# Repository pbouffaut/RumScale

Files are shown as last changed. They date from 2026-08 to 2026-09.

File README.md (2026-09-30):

# RumScale

**Manuel d’utilisation : [Français](https://pbouffaut.github.io/RumScale/) ·
[English](https://pbouffaut.github.io/RumScale/en/) ·
[Kréyòl Gwadloup](https://pbouffaut.github.io/RumScale/gcf/)** — première connexion,
utilisation quotidienne, Telegram, entretien, nouveau remplissage et dépannage.
Le manuel accompagne un tonneau déjà préparé ; le montage et les réparations
sont regroupés dans une annexe technique.

Un tonneau de vieillissement posé sur une base qui le pèse. Il sait combien il
reste dedans, depuis combien de jours le rhum vieillit, et il prévient quand le
niveau baisse.

- **Écran couleur** sur le tonneau : jauge de tonneau qui se vide, niveau en %,
  jours de vieillissement et réveil par deux coups brefs sur la base. Un bouton
  optionnel permet de parcourir les pages et de remettre le vieillissement à zéro.
- **App web** servie par l'ESP32 lui-même : jauge, historique, journal des
  services, assistant d'initialisation. Aucune application à installer — ça
  s'ouvre dans le navigateur, sur iPhone comme sur Android.
- **Alertes Telegram** à chaque service et aux seuils de 50 %, 25 % et 10 %.

---

## 1. Matériel

| Élément | Détail |
|---|---|
| Carte | **ideaspark ESP32 avec écran ST7789 1,9" 170×320 intégré** (cible principale). L'ESP32 et l'écran sont sur la même carte, déjà câblés. |
| 1 × HX711 | module ampli/ADC, canal A actif dans le firmware |
| 4 × demi-cellules de charge | réunies en **un pont complet** connecté au HX711 ; configuration actuelle du tonneau de 2 L |
| Bouton optionnel | poussoir momentané, câblé vers la masse ; inutile pour le réveil par double coup et l'utilisation de l'app web |
| Base | deux plaques rigides (contreplaqué 18 mm ou alu) + entretoises + vis M4/M5 |
| Alimentation | USB 5 V, 1 A suffit |

Une variante à **deux cellules à quatre fils (deux ponts complets)** reste
possible : une cellule par HX711, soit deux modules, avec `NUM_CHANNELS` réglé
à `2` dans [config.h](src/config.h), puis recompilation et recalibration.

Deux autres combinaisons sont maintenues dans le même code, avec un écran OLED
SSD1306 0,96" I²C à la place : un ESP32-WROOM-32 nu, ou un ESP32-S3 nu (Waveshare
ESP32-S3-DEV-KIT, Freenove ESP32-S3-WROOM). Voir la section 4.

**Pourquoi un petit écran plutôt qu'une dalle 4,3"** — au-delà de l'allure, une
dalle de 4,3" tire 150 à 250 mA en permanence et réchauffe la base de quelques
degrés. Or la dérive thermique des cellules de charge est exactement ce que
l'algorithme de la section 9 passe son temps à compenser. Sur la cible ideaspark,
le rétroéclairage est d'ailleurs piloté en PWM et volontairement réglé à 170/255
(`TFT_BACKLIGHT` dans [config.h](src/config.h)).

## 2. Câblage

Tout est en 3,3 V. **N'alimente pas les HX711 en 5 V** : leur sortie DOUT
suivrait le 5 V et attaquerait les GPIO de l'ESP32 hors spécification. On perd un
peu de signal en 3,3 V, largement compensé par la résolution du HX711.

Sur la carte ideaspark, l'écran occupe déjà les GPIO 2, 4, 15, 18, 23 et 32.
Le montage actuel utilise **un HX711 : DOUT sur GPIO 25, SCK sur GPIO 26,
VCC sur 3V3 et GND sur GND**. Les quatre demi-cellules forment ensemble le pont
raccordé à ses bornes E+, E−, A+ et A− ; elles ne correspondent pas à quatre
canaux du firmware. `NUM_CHANNELS` vaut déjà `1`.

> **[Fiche de câblage](docs/cablage.html)** — raccordement du montage actif et
> schéma de la variante à deux HX711, avec sa base à deux barres à flexion.

| Signal | ideaspark (ST7789) | ESP32-WROOM + OLED | ESP32-S3 + OLED |
|---|---|---|---|
| HX711 **A** — DOUT | 25 | 16 | 4 |
| HX711 **A** — SCK | 26 | 4 | 5 |
| HX711 **B** — DOUT (option) | 16 | 17 | 6 |
| HX711 **B** — SCK (option) | 17 | 5 | 7 |
| OLED — SDA / SCL | — | 21 / 22 | 8 / 9 |
| Bouton | 27 | 27 | 10 |
| VCC des HX711 | 3V3 | 3V3 | 3V3 |
| GND | GND commun, obligatoire | | |

Pour une **cellule à quatre fils formant déjà un pont complet** (variante), le
code couleur le plus répandu est le suivant. Ce tableau ne décrit pas les
liaisons individuelles des quatre demi-cellules du montage actuel :

| Fil | Borne HX711 |
|---|---|
| rouge | E+ |
| noir | E− |
| blanc | A− |
| vert | A+ |

> Si le poids diminue quand tu appuies sur le plateau, inverse vert et blanc sur
> ce HX711. Les codes couleur varient d'un fabricant à l'autre.

Le brochage se change en haut de [config.h](src/config.h). `NUM_CHANNELS`
désigne le nombre de **modules HX711** : `1` pour le montage actuel (ou une
seule cellule à pont complet), `2` pour deux modules. Le HX711 B n'est lu que
dans ce dernier cas.

## 3. La base mécanique — la partie qui compte vraiment

Dans le montage actuel, les quatre demi-cellules doivent porter le plateau et
pouvoir se déformer, sans appui parasite ni câble tendu. Respecte le montage
mécanique prévu pour leur forme. La coupe ci-dessous décrit la **variante à
deux barres à flexion**, pas les quatre demi-cellules.

Une cellule à flexion ne mesure que si elle peut **fléchir**. Elle se monte en
porte-à-faux : une extrémité vissée sur la plaque du bas, l'autre sur la plaque
du haut, avec de l'air entre les deux.

```
        plateau (le tonneau est posé dessus)
   ═══════════════════════════════════════════
     │ entretoise            entretoise │
     ▓▓▓▓▓▓▓▓▓▓▓            ▓▓▓▓▓▓▓▓▓▓▓        <- cellules de charge
              │ entretoise │
   ═══════════════════════════════════════════
        plaque de fond (posée au sol)
```

Quatre règles, dans l'ordre d'importance :

1. **Le plateau ne doit toucher que les cellules.** Aucun autre point de contact,
   aucun câble coincé, aucune vis qui frotte : tout appui parasite se soustrait
   directement de la mesure.
2. **Entretoises des deux côtés de chaque cellule**, pour que la barre travaille
   dans le vide. Une cellule vissée à plat sur toute sa longueur ne mesure rien.
3. **Serre fort.** Une vis qui se desserre lentement, c'est une dérive lente.
4. **Cellules symétriques**, de part et d'autre du centre, et le tonneau posé
   toujours au même endroit — c'est ce qui rend une pente de calibration unique
   suffisante.

Passe les câbles sans tension et fixe l'électronique sur la plaque du bas.

## 4. Compiler et flasher

PlatformIO Core s'installe sur macOS avec Homebrew :

```bash
brew install platformio
```

Dans ce dépôt, la carte principale est déjà sélectionnée par les commandes du
`Makefile` :

```bash
make build       # compiler pour la carte ideaspark
make ports       # afficher les ports USB/série détectés
make upload      # compiler et flasher
make monitor     # ouvrir le journal série à 115200 bauds
make deploy      # flasher puis ouvrir le journal série
make build-all   # vérifier les trois variantes matérielles
```

Pour utiliser exceptionnellement une autre cible :

```bash
make upload ENV=esp32dev
make upload ENV=esp32s3
```

Le moniteur série se ferme avec `Ctrl-C`. Si le téléversement reste sur
`Connecting…`, maintenir le bouton **BOOT**, lancer `make upload`, puis relâcher
BOOT dès que l'écriture commence. Ne pas installer de pilote USB avant d'avoir
branché la carte et vérifié `make ports` : certaines révisions utilisent CH340,
d'autres CP210x, et macOS peut déjà reconnaître la puce.

Trois cibles, une seule base de code. Choisis la tienne avec `-e` :

```bash
pio run -e ideaspark -t upload
```

```bash
pio run -e esp32dev -t upload
```

```bash
pio run -e esp32s3 -t upload
```

`ideaspark` = ESP32-WROOM-32 + écran couleur ST7789 1,9". `esp32dev` = ESP32-WROOM-32
+ OLED SSD1306. `esp32s3` = ESP32-S3 nu + OLED SSD1306. Le brochage de chacune est
dans [config.h](src/config.h), l'interface locale dans
[ui_tft.cpp](src/ui_tft.cpp) ou [ui_oled.cpp](src/ui_oled.cpp) selon la cible.

Le HTML de l'app est embarqué dans le firmware, il n'y a **pas** de
`pio run -t uploadfs` à faire. LittleFS ne sert qu'à l'historique et se formate
tout seul au premier démarrage.

Console série pour suivre ce qui se passe :

```bash
pio device monitor
```

Pour retoucher l'app sans flasher, un simulateur sert la même page avec des
données inventées — 95 jours d'historique et une dizaine de services :

```bash
python3 tools/mock_ui.py
```

## 5. Premier démarrage

1. L'ESP32 ouvre un réseau Wi-Fi ouvert nommé **`RumBarrel-setup`**, et l'écran
   l'affiche.
2. Avec un téléphone, rejoins ce réseau : la page de configuration s'ouvre
   d'elle-même. Choisis le Wi-Fi de la maison et saisis le mot de passe.
3. L'ESP32 se connecte au réseau. Ouvre `http://rum.local` dans le navigateur
   d'un téléphone connecté au même Wi-Fi ; l'IP indiquée dans la console série
   fonctionne aussi.
4. Si un bouton est installé, ses appuis courts donnent accès à la page réseau :
   elle affiche l'IP et un **QR code** pour ouvrir l'app.

Si le Wi-Fi n'est pas configuré dans les 5 minutes, l'appareil reste en point
d'accès autonome : l'app fonctionne en s'y connectant, mais sans alertes
Telegram.

## 6. Initialisation (à faire une fois)

Onglet **Réglages** de l'app, section *Initialisation*. Le poids brut s'affiche
en direct en haut, ce qui permet de vérifier chaque étape.

1. **Base vide** → *Faire le zéro*.
2. **Poids connu** → pose un objet pesé précisément (au moins 100 g),
   attends que la mesure se stabilise, saisis sa masse réelle, contenant compris,
   puis *Calibrer la balance*.
3. **Tonneau vide** → pose le tonneau vide, bonde et robinet compris, attends la
   stabilisation, *Enregistrer le tonneau vide*.
4. **Tonneau plein** → remplis, repose, attends, saisis la capacité, *Enregistrer
   le tonneau plein*. La densité réelle du liquide est calculée au passage.

> **Tonneau neuf** : le bois s'imbibe pendant les premières semaines et gagne
> plusieurs centaines de grammes. Le niveau affiché sera alors un peu optimiste.
> Quand le tonneau sera vidé une première fois, refais l'étape 3 avec le tonneau
> vide mais imbibé : les mesures suivantes seront justes.

## 7. Au quotidien

**La veille sur la carte ideaspark :** après 5 minutes par défaut, seul le
rétroéclairage s'éteint ; la pesée, le Wi-Fi et les alertes continuent. Le délai
se règle dans l'app web : jamais, 1, 5, 10, 30 ou 60 minutes. Deux
coups brefs sur la base réveillent l'écran. Ils ne changent pas de page.

**Le bouton, s'il est installé :**

- appui court → réveil si l'écran ideaspark est éteint ; sinon page suivante
  (niveau → vieillissement → réseau → diagnostic, puis retour automatique au
  bout de 30 s) ;
- appui maintenu 3 s → l'écran demande confirmation, une barre se remplit ;
- maintenu jusqu'à 6 s → le compteur de vieillissement repart à J+0 ;
- relâché avant la fin → rien ne se passe.

**L'app** se met à jour en direct par WebSocket. Le graphique montre le niveau en
litres, un point par heure, avec les marches d'escalier de chaque service.

## 8. Alertes Telegram

1. Sur Telegram, écris à **@BotFather**, envoie `/newbot`, suis les questions,
   récupère le jeton.
2. Écris un message à ton nouveau bot (sinon il ne peut pas t'écrire en premier).
3. Ouvre **@userinfobot** pour lire ton identifiant numérique.
4. Colle les deux dans l'app, *Enregistrer*, puis *Envoyer un test*.

Le jeton est stocké dans l'ESP32 et n'est jamais renvoyé par l'API — l'app
affiche seulement s'il est configuré ou non.

## 9. Comment le niveau est calculé

C'est le cœur du projet, et ce n'est pas une simple soustraction.

Une cellule de charge chinoise qui porte une charge statique pendant des mois
**dérive** : la température fait varier la sensibilité, et le métal flue sous
contrainte constante. Afficher le poids absolu brut donnerait un niveau qui
s'éloigne lentement de la réalité.

Le firmware raisonne donc en **paliers** :

- 10 mesures par seconde et par HX711, médiane glissante sur 15 valeurs puis
  lissage exponentiel ;
- quand le poids reste dans une fenêtre de 12 g pendant 20 s, le palier est figé ;
- l'écart avec le palier précédent devient un **événement** ;
- moins de 25 g d'écart → de la dérive, absorbée sans rien signaler ;
- une baisse importante mais très étalée (moins de 25 g/jour) → la **part des
  anges**, comptabilisée à part, sans alerte ;
- une baisse franche → un **service**, journalisé et notifié ;
- une hausse franche → un **remplissage**.

Un verre posé sur la base produirait une hausse puis une baisse équivalentes. Un
événement attend donc 3 minutes avant d'être validé : si son opposé arrive
entre-temps, les deux disparaissent. C'est pour cela qu'une alerte de service
arrive quelques minutes après le fait, et non instantanément.

Tous ces seuils sont regroupés et commentés dans [config.h](src/config.h).

## 10. Après une coupure de courant

Rien d'important ne vit en RAM. Voici précisément ce qui se passe au rallumage.

**Conservé tel quel** (NVS, survit à tout sauf une remise à zéro d'usine) : la
tare et la pente de calibration, les poids vide et plein, la capacité, la densité,
le nom, le jeton Telegram, le cumul d'évaporation, le dernier seuil d'alerte
franchi — et **la date de début de vieillissement**.

**Le compteur de jours est recalculé, pas incrémenté.** On stocke une date
absolue, pas un compteur : l'appareil peut rester débranché trois semaines, au
retour il affichera le bon nombre de jours. C'est aussi pourquoi il a besoin de
l'heure — voir plus bas.

**Conservé sur LittleFS** : l'historique du niveau et le journal des événements.
Le dernier service affiché est relu depuis ce journal au démarrage.

**Ce qui reste inévitablement perdu :**

- **Un trou dans la courbe** pendant la durée de la coupure. Le graphique relie
  les deux points de part et d'autre par une droite.
- **Les services survenus pendant la coupure ne déclenchent aucune alerte.** Au
  premier palier stable, le firmware compare le poids au dernier point
  d'historique. Si la baisse est lente, elle est mise au compte de la part des
  anges. Si elle est trop rapide pour ça, il consigne un manque d'origine
  indéterminée mais **n'invente jamais un service** : un tonneau soulevé et
  reposé pendant la coupure suffirait à en fabriquer un faux.
- **Jusqu'à six heures de cumul d'évaporation**, qui n'est sauvegardé qu'à
  intervalles espacés pour épargner la mémoire NVS. Quelques grammes.

**Si le Wi-Fi ne revient pas**, l'appareil n'a aucun moyen de connaître l'heure —
il n'y a pas de pile de sauvegarde. Dans ce cas l'écran affiche « en cours » et
non « J+0 » : rien n'est perdu, la date de départ est bien en mémoire, seul le
calcul attend l'heure. Et si tu remets le vieillissement à zéro dans cet état, la
demande est enregistrée puis datée dès que l'heure arrive.

Ajouter un module RTC DS3231 sur l'I²C serait la façon de rendre l'appareil
complètement autonome vis-à-vis du réseau.

> **Note pour le développement** : toute modification de la structure `Settings`
> dans [store.h](src/store.h) oblige à incrémenter `MAGIC` dans
> [store.cpp](src/store.cpp), et cela force une recalibration. C'est voulu :
> relire un ancien format de travers donnerait une balance qui mesure faux sans
> le dire.

## 11. Dépannage

| Symptôme | Piste |
|---|---|
| Page *Diagnostic* : `HX A:--` | câblage DOUT/SCK, ou HX711 non alimenté |
| Le poids diminue quand on appuie | inverse les fils vert et blanc de cette cellule |
| Valeur qui saute de plusieurs dizaines de grammes | câble de cellule qui bouge, vis desserrée, ou plateau qui touche autre chose que les cellules |
| Poids toujours à 0 | il manque le GND commun entre l'ESP32 et les HX711 |
| Image décalée horizontalement sur le ST7789 | c'est le décalage de colonne : la dalle fait 170 px sur un contrôleur câblé pour 240. Essaie `TFT_COL_OFFSET` à `0` au lieu de `35` dans [config.h](src/config.h) |
| Écran ST7789 noir | vérifie `TFT_BACKLIGHT` (0 = éteint) et que la carte est bien la version 1,9" 170×320 |
| `esp32-hal-periman.h: No such file` à la compilation | Arduino_GFX a été remonté au-delà de la 1.4.x. Depuis la 1.5, il exige le core Arduino 3.x, absent de la plateforme espressif32 6.x. Garde la borne `~1.4.0` dans platformio.ini |
| Écran OLED noir | adresse I²C : certains modules sont en 0x3D. `u8g2.setI2CAddress(0x3D * 2)` dans `Ui::begin()` |
| `heure non synchronisée` | pas d'accès Internet ; le niveau fonctionne, mais les dates et le compteur de jours attendent le NTP |
| Le % dépasse 100 après un remplissage | refais l'étape 4 : le repère « plein » date d'avant |
| Rien dans le graphique | normal au début, un point par heure |

## 12. Ce que ce projet ne fait pas

- **Aucune authentification sur l'app.** Toute personne sur le réseau local peut
  l'ouvrir, et donc recalibrer la balance. C'est un tonneau, pas un coffre-fort —
  mais ne l'expose pas sur Internet, et ne redirige aucun port vers lui.
- **Pas de compensation de température.** Ajouter un DS18B20 collé sur une
  cellule et corriger la pente serait la première amélioration à faire si la
  dérive saisonnière devient gênante.
- **Pas d'horloge sauvegardée.** Après une coupure de courant, les dates
  reviennent avec le Wi-Fi et le NTP. Le compteur de vieillissement est stocké en
  date absolue, il ne se perd pas.

## 13. Boîtier tonneau — impression 3D (V2)

Le [dossier du boîtier V2](hardware/tonneau_v2) contient les cinq STL, le modèle
paramétrique, les aperçus et les rapports de vérification géométrique.
Le boîtier mesure environ **74 × 82 × 75 mm**, avec une fenêtre écran de
**46 × 25 mm à 30°**, un passage USB rapproché et deux supports pour vis M2 × 5 mm
espacés de 26 mm. Les deux moitiés s'emboîtent sans colle et laissent de la place
pour les connecteurs Dupont derrière la carte.

- [Télécharger le pack STL et guide](hardware/tonneau_ESP32_V2_STL_et_guide.zip).
- [Lire le guide d'impression et de montage](hardware/tonneau_v2/LIRE_AVANT_IMPRESSION_V2.md).
- [Coque basse](hardware/tonneau_v2/01_demi_tonneau_bas_v2.stl) et
  [coque haute](hardware/tonneau_v2/02_demi_tonneau_haut_v2.stl).
- [Gabarit de vérification de la carte et des vis](hardware/tonneau_v2/03_gabarit_carte_et_vis_v2.stl).

Imprimer d'abord le gabarit pour vérifier l'ajustement avec la carte réelle.
Les contrôles numériques ne remplacent pas cet essai physique. Les coques V1 et
V2 ne sont pas interchangeables : les deux moitiés doivent être imprimées en V2.

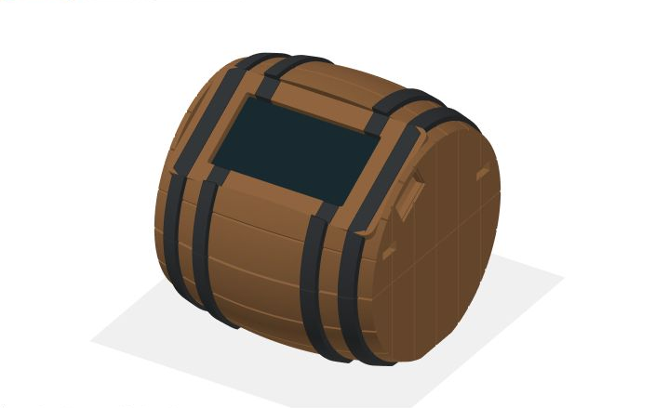
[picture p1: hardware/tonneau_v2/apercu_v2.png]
Aperçu du boîtier tonneau V2


## Documentation publique

Le manuel au thème pirate s’adresse à la personne qui utilise le tonneau. Il est
disponible en trois langues, avec sa FAQ et ses annexes :

- Français : `docs/index.html`, `docs/maintenance.html` et `docs/cablage.html`.
- Anglais : `docs/en/index.html`, `docs/en/maintenance.html` et `docs/en/cablage.html`.
- Créole guadeloupéen : `docs/gcf/index.html`, `docs/gcf/maintenance.html` et `docs/gcf/cablage.html`.

Le parcours normal conserve la calibration et le vieillissement d’un tonneau
déjà préparé. L’initialisation est une procédure à consulter seulement au besoin.
Les pages `maintenance.html` regroupent l’impression 3D, le montage électronique
et les mises à jour ; les pages `cablage.html` en détaillent les schémas.

Les styles, illustrations et la recherche locale sont partagés dans `docs/assets/`.
La police est fournie localement, avec sa licence dans `docs/assets/fonts/OFL.txt`.
Le site ne dépend d'aucun service externe pour ses polices ou sa recherche.
Le sélecteur de langue conserve le lien vers la section sélectionnée. Les libellés
des commandes de l'application restent en français pour correspondre à l'ESP32.

Aucune compilation du site n'est nécessaire. GitHub Pages publie le dossier
`/docs` de la branche `main` ; les modifications poussées sur cette branche mettent
le guide à jour. Lors d'une modification des instructions, mettre à jour les trois
versions et garder leurs identifiants de section identiques.

Pour le consulter avant publication :

```bash
python3 -m http.server 8769 --directory docs
```

Ouvre ensuite `http://localhost:8769`. Après modification, vérifie les liens,
l'affichage sur téléphone et la recherche dans la FAQ.

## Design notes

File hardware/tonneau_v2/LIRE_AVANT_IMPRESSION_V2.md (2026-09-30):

# Tonneau ESP32 — V2 compacte, carte vissée

Cette version intègre les mesures fournies après l'impression de la V1: carte de **32,6 mm** de large, ensemble écran/carte de **5 mm** d'épaisseur, entraxe de fixation de **26 mm**, boutons Reset/Boot contenus dans une largeur de **22 mm**, écran utile de **46 × 25 mm**.

## Modifications

| Élément | V1 | V2 |
|---|---:|---:|
| Longueur du tonneau | 96 mm | 74 mm |
| Largeur extérieure | Environ 88 mm | Environ 82 mm |
| Hauteur extérieure | 78 mm | 75 mm |
| Retrait nominal du port USB par rapport au bout du tonneau | 16,1 mm | 5,1 mm |
| Passage USB intérieur | 16 × 12 mm | 13 × 8 mm |
| Bouche USB extérieure | 18 × 14 mm | 13,8 × 8,8 mm |
| Fenêtre écran | 52 × 26,6 mm | **46 × 25 mm** |
| Position de la fenêtre | Référence V1 | Décalée de **3 mm vers l'USB** pour masquer la marque |
| Largeur du logement | 33 mm | 34 mm pour la carte de 32,6 mm |
| Fixation de la carte | Colle chaude | **Deux supports de vis intégrés**, entraxe 26 mm |

Le plan de l'écran reste à **30° de la table**. Le fond reste plat, les fils sortent par le passage arrière de 10 mm, et les deux coques se ferment avec quatre clips sans colle. Le volume prévu derrière la carte reste profond de **36 mm**. Les clips sont placés plus bas pour que leur flexion ne touche ni les nouveaux supports, ni la carte, ni les têtes de vis.

**Les coques V1 et V2 ne sont pas interchangeables. Il faut réimprimer les deux moitiés V2.** Les fichiers V1 sont conservés séparément.

## Fichiers

- `01_demi_tonneau_bas_v2.stl`: imprimer une fois.
- `02_demi_tonneau_haut_v2.stl`: imprimer une fois.
- `03_gabarit_carte_et_vis_v2.stl`: essai de la fenêtre, du logement et des deux supports de vis.
- `04_test_clip_male_v2.stl` et `05_test_clip_femelle_v2.stl`: essai facultatif du nouvel emplacement des clips.
- `tonneau_v2_parametrique.py`: modèle modifiable.
- `verification_geometrique.json`: contrôle des solides et des STL relus après export, avec empreinte de chaque fichier.

Unités: **millimètres**, échelle **100 %**. Les STL sont déjà orientés pour l'impression: bas sur son fond plat; haut sur son plan de joint; gabarit face visible sur le plateau.

## Fixation de la carte

Prévoir **deux vis M2 × 5 mm**, à tête plate dessous (tête cylindrique ou bombée, pas fraisée). Les avant-trous des supports font **1,6 mm** et sont aveugles. Visser doucement dans le plastique, sans insert ni écrou. Le vissage se fait depuis le dos du circuit imprimé, à l'intérieur de la coque haute.

Les deux plots portent sur le PCB côté écran, autour des deux trous de part et d'autre de l'USB. Ils ont un méplat vers les boutons pour laisser 0,5 mm autour de leur enveloppe mesurée. Les vis et les plots restent en dehors de la zone visible de l'écran.

Le doré dans l'aperçu intérieur sert uniquement à repérer les plots: ceux-ci sont imprimés avec la coque, sans pièce métallique à ajouter. Les couleurs des cerclages sont également illustratives.

1. Imprimer le gabarit avec le filament et les réglages destinés au boîtier.
2. Insérer la carte par l'arrière, USB vers les deux plots. Vérifier que la fenêtre montre l'écran, couvre la marque et n'appuie pas sur le verre.
3. Présenter les deux vis dans les trous de la carte. Vérifier leur alignement avec les avant-trous et le contact des deux plots avec le PCB. Ne pas tirer sur la carte avec les vis pour corriger un défaut de position.
4. Serrer seulement jusqu'au maintien de la carte. Vérifier que le cadre de l'écran repose sur sa butée sans flexion du PCB ou pression sur le verre.
5. Après impression de la coque haute, monter la carte et vérifier l'insertion de la fiche USB avant de refermer le tonneau. Brancher les Dupont, ranger les fils loin des clips, puis emboîter les deux coques.

Le tunnel USB laisse passer un surmoulage jusqu'à 13 × 8 mm en nominal. Le centrage réel de la prise et le jeu d'impression réduisent cette enveloppe; essayer la fiche utilisée. Une fiche de 6–7 mm de haut laisse davantage de marge qu'une fiche de 8 mm. Le port est rapproché de 11 mm de la paroi par rapport à la V1.

## Impression

Conserver un profil d'impression déjà maîtrisé. Point de départ: buse 0,4 mm, couches 0,20 mm, quatre parois, cinq couches pleines dessus/dessous et 15–20 % de remplissage. Le PETG offre davantage de souplesse aux clips; avec un filament bois ou du PLA, vérifier leur comportement sur le coupon.

La coque haute demande des supports sous la voûte et certains rebords; vérifier également les surplombs des extrémités du bas. Éviter d'enfermer des supports dans les avant-trous de vis. Retirer toutes les bavures avant d'emboîter les coques. Le gabarit est conçu pour être imprimé face visible sur le plateau, sans support sous les plots.

## Mesures et limites

Mesures utilisateur intégrées: largeur 32,6 mm, épaisseur totale 5 mm, entraxe 26 mm, largeur extérieure des boutons 22 mm et écran 46 × 25 mm. La longueur de 63,8 mm est celle de l'image produit initiale.

Les cotes non mesurées directement restent explicites: épaisseur du PCB supposée de **1,6 mm**, axe des trous situé à **2,1 mm du petit bord côté USB**, centre en hauteur du port estimé d'après les photos. Le diamètre réel des trous de la carte n'a pas été fourni; les vis M2 sont choisies pour laisser du jeu dans les trous visibles. Ces points sont vérifiables sur le gabarit avant les grandes pièces.

Les vérifications numériques portent sur les maillages, l'emboîtement au repos, l'espace derrière la carte et le dégagement des clips vis-à-vis de la carte, des plots et des têtes de vis. Une seconde lecture indépendante des STL a confirmé leur fermeture et le dégagement des quatre clips sur une enveloppe continue de flexion de 1,3 mm. Une fiche théorique de 12 × 6 mm passe sans collision. Ces contrôles ne constituent pas un essai physique de cette V2 ni une simulation de résistance des matériaux.

Pour régénérer, installer les dépendances de `requirements_cad_v2.txt` puis exécuter `tonneau_v2_parametrique.py` avec Python 3.11 ou plus récent. Les mesures et les hypothèses figurent dans le dictionnaire `P` au début du fichier.

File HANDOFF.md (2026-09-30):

# Passation — RumScale

Pour l'assistant qui reprend ce projet. Le [README](README.md) explique comment
monter et utiliser l'appareil ; ce document-ci explique **l'état réel du code, les
décisions non évidentes et les pièges déjà payés**. Lis-le avant de modifier quoi
que ce soit.

---

## 1. Contexte historique et portée des vérifications

Cette passation a été rédigée lors de la préparation initiale, avant l'achat de
la carte. Les mentions de « premier flash » ci-dessous viennent de cette phase
et ne décrivent plus l'état actuel du projet : des essais matériels ont eu lieu
depuis. Cette mise à jour documentaire n'ajoute aucune nouvelle validation sur
l'appareil.

Vérifications consignées lors de la préparation initiale :

- les trois cibles compilent (`ideaspark`, `esp32dev`, `esp32s3`) ;
- l'app web a été testée dans un navigateur contre un simulateur HTTP
  (`tools/mock_ui.py`), y compris les états dégradés ;
- la géométrie de l'écran couleur a été contrôlée en reconstruisant le layout en
  SVG à partir des constantes du source.

La lecture des HX711, l'affichage ST7789, le bouton, le Wi-Fi, Telegram, la
persistance NVS/LittleFS et le cycle extinction/rallumage n'étaient pas vérifiés
à cette date. Ce relevé historique ne suffit donc ni à certifier le firmware
actuel, ni à affirmer que ces fonctions n'ont jamais été essayées.

La configuration actuelle dans `config.h` est la carte ideaspark avec quatre
demi-cellules réunies en un pont complet, un HX711 A sur DOUT 25 / SCK 26 et
`NUM_CHANNELS = 1`. Le HX711 B sur 16/17 reste optionnel. Le rétroéclairage
se met en veille après un délai réglable et se réveille par deux coups brefs ;
le bouton reste optionnel pour la navigation des pages. Pour une nouvelle carte
ou un changement de montage, reprendre les points de contrôle du §6.

---

## 2. Ce que fait l'appareil

Un tonneau de vieillissement (cadeau) posé sur une base qui le pèse en continu.
Quatre demi-cellules réunies en un pont complet → un HX711 → un ESP32 qui en
déduit le volume restant, compte les jours de vieillissement, sert une app web,
et prévient par Telegram quand quelqu'un se sert. La variante initiale à deux
cellules à pont complet et deux HX711 nécessite `NUM_CHANNELS = 2`.

## 3. Architecture

Un module par responsabilité, sans framework, tout en `namespace` (pas de
classes — il n'y a qu'une instance de chaque chose).

| Fichier | Rôle |
|---|---|
| `main.cpp` | `setup()` / `loop()`, cinq appels, rien d'autre |
| `config.h` | **tout le brochage et tous les seuils**, par cible (`#if defined(BOARD_*)`) |
| `store.{h,cpp}` | réglages persistants (NVS), blob binaire et délai de veille dans une clé séparée |
| `scale.{h,cpp}` | lecture non bloquante des HX711, médiane + lissage, calibration |
| `barrel.{h,cpp}` | **le cœur métier** : paliers, événements, volume, vieillissement |
| `history.{h,cpp}` | anneaux sur LittleFS : points horaires + journal d'événements |
| `button.{h,cpp}` | antirebond et appui long, partagé par les deux interfaces |
| `ui_tft.cpp` | interface ST7789 couleur (cible `ideaspark`) |
| `ui_oled.cpp` | interface OLED SSD1306 (cibles `esp32dev`, `esp32s3`) |
| `ui.h` | l'interface commune aux deux ci-dessus |
| `net.{h,cpp}` | Wi-Fi, portail de configuration, serveur web, WebSocket, API REST |
| `notify.{h,cpp}` | file d'attente Telegram |
| `web_ui.h` | l'app web entière (HTML+CSS+JS) en PROGMEM |

`ui_tft.cpp` et `ui_oled.cpp` sont tous deux gardés par `#if defined(BOARD_*)` :
PlatformIO compile tout `src/`, la sélection se fait donc dans le fichier.

---

## 4. Les décisions non évidentes

Chacune a une raison. Si tu veux en défaire une, sache ce que tu casses.

### On ne se fie jamais au poids absolu instantané

Une cellule de charge sous charge statique **dérive** pendant des mois
(température, fluage du métal). Afficher le poids brut donnerait un niveau qui
s'éloigne lentement du réel.

D'où la machine à paliers dans `barrel.cpp` : quand le poids reste dans une bande
de 12 g pendant 20 s, le palier est figé ; l'écart avec le palier précédent
devient un événement. Sous 25 g d'écart, c'est de la dérive. Une baisse lente
(< 25 g/jour) est de l'évaporation ; une baisse franche est un service.

**Ne remplace pas ça par une comparaison de poids absolu.** C'est la valeur
centrale du projet.

### Un événement attend 3 minutes avant d'être confirmé

Un verre posé sur la base produit une hausse puis une baisse équivalentes. Un
événement qui se fait annuler par son opposé dans la fenêtre disparaît, les deux.
C'est pourquoi une alerte Telegram arrive **quelques minutes après** le service,
et non instantanément. Ce délai est voulu (`EVENT_CONFIRM_MS`).

### Au redémarrage, on ne fabrique jamais un service

`reconcileAfterBoot()` compare le poids au dernier point d'historique pour
rattraper l'évaporation survenue hors tension. Si l'écart est trop rapide pour de
l'évaporation, il journalise un manque « d'origine indéterminée » et **n'invente
pas de service** : un tonneau soulevé puis reposé pendant la coupure suffirait à
en créer un faux, avec alerte à la clé.

### `agingDays()` a trois retours, pas deux

`AGING_NEVER` (−1) et `AGING_UNKNOWN` (−2) sont distincts. Renvoyer `0` quand
l'heure n'est pas synchronisée afficherait « J+0 » à quelqu'un dont le rhum
vieillit depuis trois mois — c'est le pire message possible. Les trois interfaces
(TFT, OLED, web) traitent explicitement `−2`.

De même, `resetAging()` sans heure n'écrit pas `0` (qui signifie « jamais
démarré ») : il pose `agingPending`, que `resolveAgingPending()` date au retour
du NTP.

### Une seule pente de calibration pour les canaux actifs

`grams()` fait `(Σ(brut − offset)) / countsPerGram`. Dans le montage actif,
le pont complet est lu par un seul HX711. Dans la variante à deux modules,
cette calibration commune suppose que la répartition de la charge est constante
— ce qui est le cas d'un tonneau qui ne
bouge plus. Calibrer chaque cellule séparément demanderait de poser un poids connu
sur chacune, sans gain réel ici.

### `MAGIC` dans `store.cpp` doit être incrémenté à chaque changement de `Settings`

Le blob NVS est relu tel quel. Un ancien blob de même taille relu au nouveau
format donnerait **une balance qui mesure faux sans le dire**. Le prix d'un
incrément est une recalibration ; le prix de l'oubli est invisible et permanent.
Actuellement : `RSC2`.

### L'app web est en PROGMEM, pas sur LittleFS

Un seul `pio run -t upload` met tout à jour, pas de `uploadfs` à oublier. Le
projet est un cadeau : chaque étape de déploiement en moins est une panne en
moins. LittleFS ne sert qu'à l'historique et se formate seul.

### `huge_app.csv`

Le firmware pèse ~1,55 Mo (TLS pour Telegram + serveur asynchrone) et ne tient pas
dans les 1,31 Mo du schéma par défaut. On perd l'OTA, dont on n'a pas l'usage.

---

## 5. Pièges déjà rencontrés — ne les repaie pas

**Arduino_GFX est figé en `~1.4.0`.** Depuis la 1.5, son pilote SPI ESP32 inclut
`esp32-hal-periman.h`, qui n'existe que dans le core Arduino 3.x, **sans garde de
version**. La plateforme `espressif32@6.x` fournit le core 2.0.17. Remonter cette
borne casse la compilation, sauf à migrer aussi vers le core 3.x (pioarduino).

**`WiFiClientSecure::setTimeout()` est en secondes**, contrairement à
`HTTPClient::setTimeout()` qui est en millisecondes. Les deux sont utilisés dans
`notify.cpp`, avec un commentaire.

**`PIN_LED` vaut −1 sur ESP32-S3.** La LED embarquée de ces cartes est une WS2812
adressable qu'un `digitalWrite` ne pilote pas. Tout le code de LED est gardé par
`if (PIN_LED >= 0)`.

**Sur ESP32-S3 à PSRAM octale (`R8`), les GPIO 33 à 37 sont pris.** Ne les utilise
jamais pour les HX711.

**Sur la carte ideaspark, l'écran occupe les GPIO 2, 4, 15, 18, 23 et 32.** Le
brochage OLED d'origine utilisait le 2 et le 4 : il a fallu déplacer les HX711.

**Une dalle ST7789 de 170 px de large exige un décalage de colonne** (`TFT_COL_OFFSET`,
à 35). Si l'image est glissée horizontalement au premier flash, c'est là.

---

## 6. Ce qui reste à faire

### Points de contrôle issus du premier montage

1. **Le décalage de l'écran.** Image glissée → passer `TFT_COL_OFFSET` de 35 à 0.
2. **La métrique verticale des polices.** `ui_tft.cpp` suppose que
   `u8g2_font_logisoso38_tn` monte 38 px au-dessus de la ligne de base. Si les
   chiffres sont rognés ou trop hauts, décaler `PCT_BASE` et ses voisines.
3. **Le sens des cellules.** Appuyer sur le plateau doit faire *monter* la valeur
   brute (page Diagnostic). Sinon, échanger vert et blanc sur le HX711 concerné.
4. **Le cycle de coupure.** Initialiser complètement, débrancher, rebrancher :
   la calibration et le nombre de jours doivent être intacts, et la tuile
   « dernier service » repeuplée depuis le journal.

### Idées non faites, par ordre d'utilité

- **Compensation de température** : un DS18B20 collé sur une cellule, et corriger
  la pente. C'est la vraie limite de précision actuelle.
- **Export/import des réglages** depuis l'app, pour survivre à un changement de
  structure `Settings` sans recalibrer.
- **Authentification** sur l'app : il n'y en a aucune. Assumé (réseau domestique,
  c'est un tonneau), mais à savoir. Ne jamais exposer l'appareil sur Internet.
- Un RTC DS3231 a été explicitement écarté par l'utilisateur : le NTP suffit,
  puisque la date de départ est stockée en absolu.

---

## 7. Travailler sans la carte

```bash
python3 tools/mock_ui.py
```

Sert la même app web que l'ESP32 (extraite de `web_ui.h`) sur
`http://127.0.0.1:8777`, avec 95 jours d'historique et une dizaine de services
inventés. Toute modification de l'app web se teste comme ça. Édite les valeurs en
haut du script pour simuler un état dégradé (`aging_days: -2` pour l'heure non
synchronisée, `pct: -1` pour un tonneau non initialisé).

Pour compiler les trois cibles :

```bash
pio run -e ideaspark && pio run -e esp32dev && pio run -e esp32s3
```

---

## 8. Conventions

- **Le code et les commentaires sont en français**, comme l'interface. Continue.
- Les commentaires expliquent **pourquoi**, jamais quoi. S'il n'y a pas de
  pourquoi, il n'y a pas de commentaire.
- Tous les seuils réglables vivent dans `config.h`, jamais en dur dans la logique.
- Les textes destinés à l'utilisateur sont en UTF-8 direct dans le source (pas de
  séquences `\xC3\xA9`) — le core ESP32 et U8g2 les gèrent.

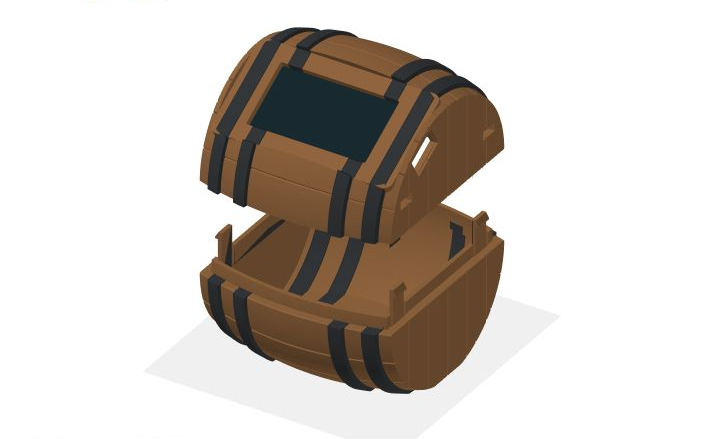
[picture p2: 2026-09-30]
hardware/tonneau_v2/apercu_v2_eclate.png

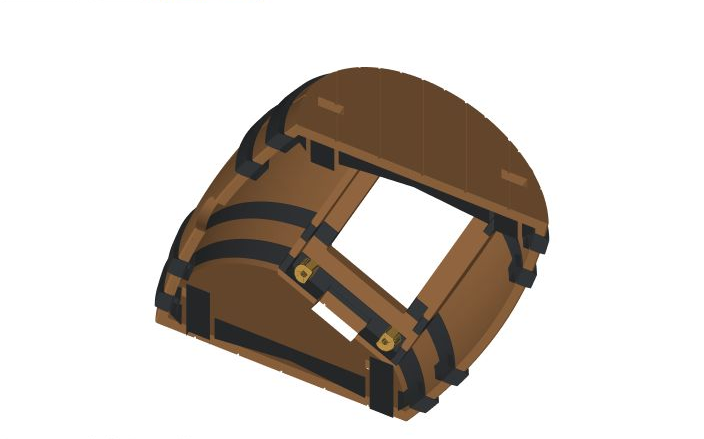
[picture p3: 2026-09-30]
hardware/tonneau_v2/apercu_v2_supports.png

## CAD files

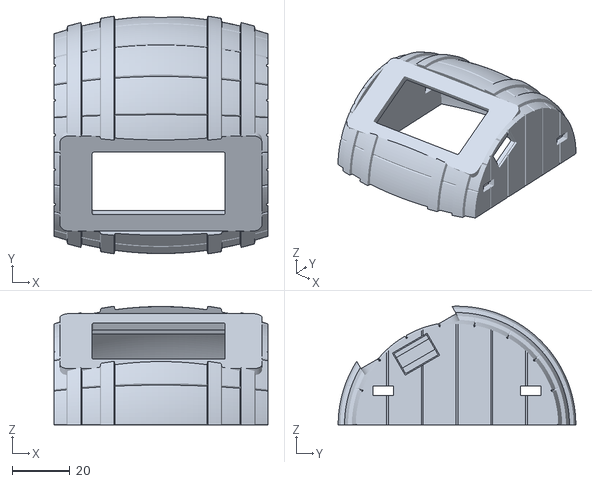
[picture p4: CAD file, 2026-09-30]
hardware/tonneau_v2/02_demi_tonneau_haut_v2.stl
74.0 x 82.2 x 41.0

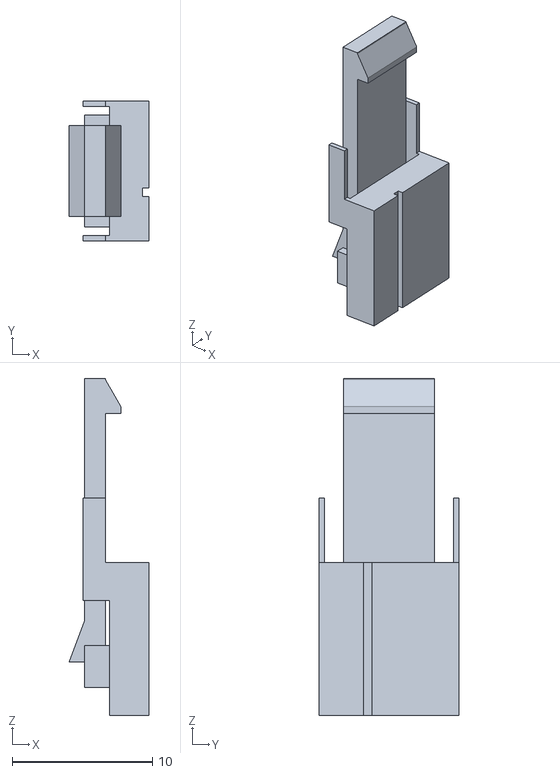
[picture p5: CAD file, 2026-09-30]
hardware/tonneau_v2/04_test_clip_male_v2.stl
5.70 x 10.0 x 24.0

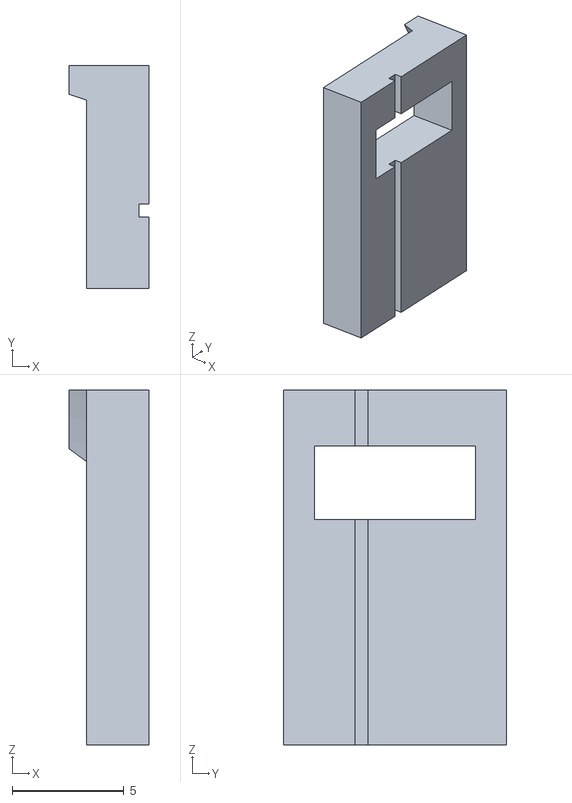
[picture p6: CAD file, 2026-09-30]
hardware/tonneau_v2/05_test_clip_femelle_v2.stl
3.60 x 10.0 x 15.9

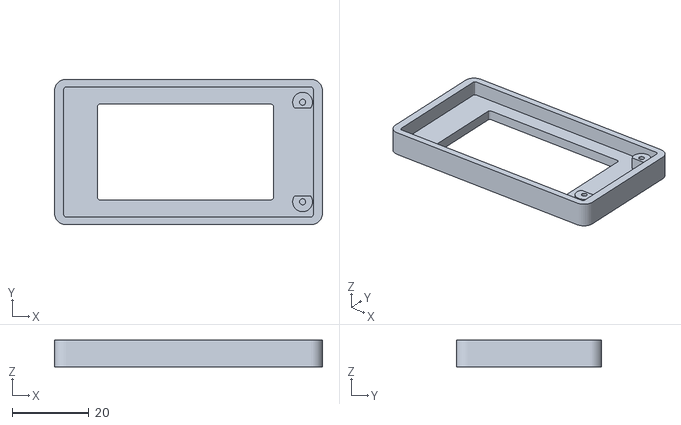
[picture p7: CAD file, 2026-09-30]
hardware/tonneau_v2/03_gabarit_carte_et_vis_v2.stl
70.0 x 38.0 x 7.00

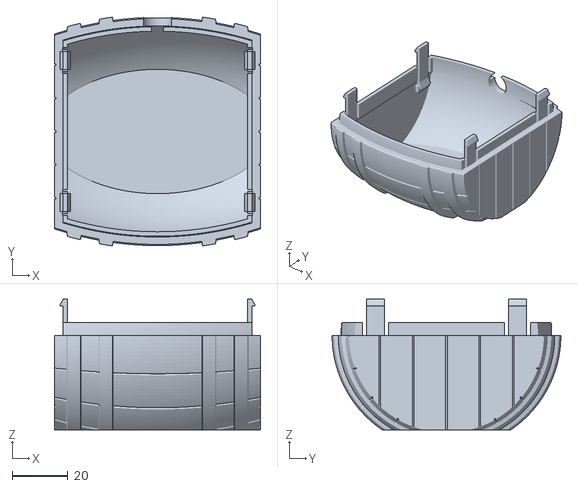
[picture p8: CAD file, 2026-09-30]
hardware/tonneau_v2/01_demi_tonneau_bas_v2.stl
74.0 x 82.2 x 47.0

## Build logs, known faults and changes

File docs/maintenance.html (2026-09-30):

Aller au contenu

 RumScaleAnnexe technique

Imprimer le manuelOuvrir mon tonneau ↗ (http://rum.local/)

Sommaire du manuel

Carte de navigation

Ton manuel, à garder près du tonneau.
Vérifié le 30 septembre 2026.

RumScale · Annexe technique

# Annexe technique

Boîtier, câblage et logiciel : les informations pour réparer ou modifier le matériel, à consulter au besoin avec la personne qui a préparé le tonneau.

← Retour au manuelFiche de câblage →

RumScale — Annexe technique · Vérifié le 30 septembre 2026.

## Boîtier tonneau imprimé en 3D

La version V2 protège la carte ideaspark tout en gardant l’écran et les connecteurs accessibles.

Télécharger les STL et le guide V2 (https://github.com/pbouffaut/RumScale/raw/refs/heads/main/hardware/tonneau_ESP32_V2_STL_et_guide.zip) · Consulter tous les fichiers du boîtier (https://github.com/pbouffaut/RumScale/tree/main/hardware/tonneau_v2).

Aperçu du boîtier tonneau V2 : écran incliné, fond plat et deux coques emboîtables.

Aperçu du modèle V2. Les couleurs illustrent les formes ; elles ne nécessitent pas de pièces métalliques.

- Dimensions extérieures d’environ 74 × 82 × 75 mm, fond plat et écran incliné de 30°.
- Fenêtre d’écran 46 × 25 mm ; logement adapté à une carte mesurée à 32,6 mm de largeur et 5 mm d’épaisseur.
- Passage USB intérieur 13 × 8 mm, port à environ 5,1 mm de l’extrémité ; passage arrière de 10 mm pour les fils.
- Deux supports intégrés espacés de 26 mm, pour deux vis M2 × 5 mm à tête cylindrique ou bombée, non fraisée.
- Deux coques assemblées par quatre clips, sans colle ; espace de 36 mm prévu derrière la carte pour les connecteurs Dupont.

### Avant l’impression complète

Imprime d’abord le gabarit de carte et de vis avec ton filament définitif. Vérifie la fenêtre, l’alignement des trous et l’appui sur le circuit. Le gabarit ne reproduit pas le tunnel USB : après impression de la coque haute, vérifie aussi l’insertion réelle de ta fiche. Les contrôles numériques du modèle ne remplacent pas ce test physique. Les coques V1 et V2 ne s’assemblent pas entre elles.

### Impression et montage

Unités : millimètres, échelle 100 %. Les fichiers sont déjà orientés : coque basse sur son fond, coque haute sur le plan de joint, gabarit face visible sur le plateau. Point de départ : buse 0,4 mm, couches de 0,20 mm, quatre parois, cinq couches pleines et 15–20 % de remplissage. Le PETG donne davantage de souplesse aux clips ; teste ceux-ci si tu choisis du PLA ou un filament bois.

Prévois des supports sous la voûte et certains rebords de la coque haute, et vérifie les surplombs de la coque basse. Nettoie les bavures. Place la carte dans la coque haute, puis visse doucement depuis le dos du circuit imprimé dans les deux avant-trous de 1,6 mm. Arrête dès que la carte tient : les vis ne doivent ni courber la carte ni mettre le verre sous pression.

Vérifie la fiche USB avant de fermer. Une fiche avec un surmoulage de 6–7 mm de haut laisse plus de marge qu’une fiche de 8 mm. Branche les Dupont, range les fils à l’écart des clips et emboîte les coques. Les boutons BOOT et EN restent des commandes de la carte, pas des boutons de configuration quotidienne.

## Montage et maintenance avancée

Ces informations s’adressent à la personne qui assemble ou entretient l’électronique. Un tonneau livré prêt à l’emploi n’en a pas besoin pour fonctionner.

### Montage actif : un seul HX711

La configuration actuelle associe une carte ideaspark ESP32-WROOM-32 avec écran ST7789 1,9″ à un HX711. Quatre demi-cellules de charge forment ensemble un seul pont de mesure ; elles ne représentent pas quatre canaux indépendants.

HX711 | Carte ideaspark
VCC | 3V3
GND | GND commun
DT / DOUT | GPIO 25
SCK | GPIO 26

Le HX711 est alimenté en 3,3 V, même si la carte reçoit du 5 V par USB. Ne raccorde pas sa sortie logique alimentée en 5 V aux broches de l’ESP32. Consulte la fiche de câblage avant d’intervenir.

### Variante : deux HX711

Une variante utilise deux cellules à pont complet, avec un HX711 par cellule. Sur la carte ideaspark, le second module utilise GPIO 16 pour DT et GPIO 17 pour SCK. Elle exige de passer NUM_CHANNELS de 1 à 2, de recompiler et de refaire la calibration. Le schéma de cette variante ne décrit pas les connexions individuelles des quatre demi-cellules du montage actif.

### Mettre à jour le logiciel

Depuis une copie du projet avec PlatformIO installé, branche la carte en USB puis utilise les commandes suivantes. Le firmware contient déjà l’app web ; aucun téléversement séparé de fichiers web n’est nécessaire.

make ports       # repérer la carte USB
make build       # compiler pour la carte ideaspark
make upload      # installer le logiciel
make monitor     # lire le diagnostic ; quitter avec Ctrl-C

Si l’installation reste sur Connecting…, maintiens BOOT au lancement du téléversement, puis relâche-le quand l’écriture commence. make build-all compile aussi les deux variantes OLED prévues dans le projet. Leur brochage est différent : vérifie la cible avant toute installation.

Une mise à jour peut conserver les réglages, mais ce n’est pas garanti si leur format a changé. Après intervention, vérifie le réseau, le poids, les repères et Telegram avant de remettre le tonneau en service.

### Diagnostic utile à transmettre

Note le symptôme, les dernières manipulations et les indications de Réglages → Système : état du HX711 et synchronisation de l’heure. Pour un diagnostic technique, la page locale http://rum.local/api/state expose les mesures brutes et l’état de l’appareil. Elle peut contenir le nom du tonneau et l’identifiant de discussion Telegram : masque ces éléments avant de la partager publiquement.

RumScale · Annexe technique
Vérifié le 30 septembre 2026.

Retour au manuel ↗Le projet sur GitHub ↗ (https://github.com/pbouffaut/RumScale)Retour en haut ↑

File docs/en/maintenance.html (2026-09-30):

Skip to content

 RumScaleTechnical appendix

Print the manualOpen my barrel ↗ (http://rum.local/)

Manual contents

Chart your course

Your manual, to keep close to your barrel.
Checked on September 30, 2026.

RumScale · Technical appendix

# Technical appendix

Enclosure, wiring and software: information for repairing or modifying the hardware, to consult when needed with the person who prepared the barrel.

← Back to the manualWiring reference →

RumScale — Technical appendix · Checked on September 30, 2026.

## 3D-printed barrel enclosure

The V2 enclosure protects the ideaspark board while keeping its screen and connectors accessible.

Download the V2 STL files and guide (https://github.com/pbouffaut/RumScale/raw/refs/heads/main/hardware/tonneau_ESP32_V2_STL_et_guide.zip) · Browse all enclosure files (https://github.com/pbouffaut/RumScale/tree/main/hardware/tonneau_v2).

Preview of the V2 barrel enclosure: tilted screen, flat base and two interlocking shells.

Preview of the V2 model. The colours illustrate its shape; no metal parts are required.

- Overall dimensions of about 74 × 82 × 75 mm, with a flat base and a screen tilted at 30°.
- 46 × 25 mm screen window; board pocket designed for a measured width of 32.6 mm and thickness of 5 mm.
- 13 × 8 mm inner USB opening, with the port about 5.1 mm from the end; a 10 mm rear opening for wires.
- Two built-in supports spaced 26 mm apart, for two M2 × 5 mm screws with cylindrical or rounded heads, not countersunk heads.
- Two shells held together by four clips, without glue; 36 mm of space behind the board for Dupont connectors.

### Before printing the complete enclosure

Print the board-and-screw fit gauge first, using your final filament. Check the window, hole alignment and where the board rests. The gauge does not reproduce the USB tunnel: after printing the upper shell, also check that your actual plug fits. Digital model checks do not replace this physical test. V1 and V2 shells do not fit together.

### Printing and assembly

Units: millimetres, scale 100%. The files are already oriented: lower shell on its flat base, upper shell on its joining face, and gauge with its visible face on the print bed. Starting settings: 0.4 mm nozzle, 0.20 mm layers, four walls, five solid layers and 15–20% infill. PETG gives the clips more flexibility; test them if you choose PLA or wood-filled filament.

Add supports under the upper shell’s arch and some of its ledges, and check the lower shell’s overhangs. Remove burrs. Place the board in the upper shell, then gently drive the screws from the back of the circuit board into the two 1.6 mm pilot holes. Stop as soon as the board is secure: the screws must not bend the board or put pressure on the glass.

Check the USB plug before closing the enclosure. A plug with a 6–7 mm-high moulded housing leaves more clearance than an 8 mm one. Connect the Dupont leads, tuck the wires away from the clips and join the shells. BOOT and EN remain board controls, not everyday setup buttons.

## Advanced assembly and maintenance

This information is for the person assembling or maintaining the electronics. You do not need it to use a barrel supplied ready to go.

### Active setup: one HX711

The current setup combines an ideaspark ESP32-WROOM-32 board with a 1.9″ ST7789 screen and one HX711. Four half-bridge load cells together form a single measurement bridge; they are not four independent channels.

HX711 | ideaspark board
VCC | 3V3
GND | Shared GND
DT / DOUT | GPIO 25
SCK | GPIO 26

The HX711 is powered at 3.3 V, even though the board receives 5 V over USB. Do not connect a logic output powered at 5 V to the ESP32 pins. Consult the wiring reference before working on it.

### Alternative setup: two HX711 modules

An alternative uses two full-bridge load cells, with one HX711 per cell. On the ideaspark board, the second module uses GPIO 16 for DT and GPIO 17 for SCK. This requires changing NUM_CHANNELS from 1 to 2, rebuilding the firmware and recalibrating. The diagram for this alternative does not show the individual connections of the four half-bridge cells in the active setup.

### Updating the software

From a copy of the project with PlatformIO installed, connect the board over USB, then use the commands below. The firmware already includes the web app; no separate upload of web files is needed.

make ports       # repérer la carte USB
make build       # compiler pour la carte ideaspark
make upload      # installer le logiciel
make monitor     # lire le diagnostic ; quitter avec Ctrl-C

The commands above identify the USB board, build the ideaspark firmware, install it and display diagnostics; exit the monitor with Ctrl-C. If installation stays on Connecting…, hold BOOT as the upload starts, then release it when writing begins. make build-all also builds the two OLED variants included in the project. Their pin assignments differ: check the target before installing anything.

A software update may preserve settings, but this is not guaranteed if their format has changed. After maintenance, check the network, weight, reference points and Telegram before putting the barrel back into use.

### Useful information for troubleshooting

Note the symptom, your recent actions and the information in Réglages → Système: HX711 status and time synchronization. For technical diagnostics, the local page http://rum.local/api/state exposes raw measurements and device status. It may include the barrel’s name and Telegram chat ID: hide those details before sharing it publicly.

RumScale · Technical appendix
Checked on September 30, 2026.

Back to the manual ↗Project on GitHub ↗ (https://github.com/pbouffaut/RumScale)Back to top ↑

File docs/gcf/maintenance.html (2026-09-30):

Alé dirèk adan manyèl-la

 RumScaleLanèks téknik

Enprimé manyèl-laWouvè barik an mwen ↗ (http://rum.local/)

Sa ki adan manyèl-la

Kat pou jwenn chimen a-w

Manyèl a-w, pou gadé owa barik-la.
Vérifyé 30 sèptanm 2026.

RumScale · Lanèks téknik

# Lanèks téknik

Bwat, kab é lojisyèl : sé lenfòwmasyon-la pou réparé oben chanjé matéryèl-la. Si ou bizwen, gadé yo èvè moun-la ki préparé barik-la.

← Viré adan manyèl-laFich kab-la →

RumScale — Lanèks téknik · Vérifyé 30 sèptanm 2026.

## Bwat an fòm barik, enprimé an 3D

Vèsyon V2 la ka pwotéjé kat ideaspark la é ka lésé-w aksè a lékran-la é sé konektè-la.

Téléchajé sé STL-la é gid V2 la (https://github.com/pbouffaut/RumScale/raw/refs/heads/main/hardware/tonneau_ESP32_V2_STL_et_guide.zip) · Gadé tout sé fichyé a bwat-la (https://github.com/pbouffaut/RumScale/tree/main/hardware/tonneau_v2).

Modèl a bwat-barik V2 la : lékran-la panché, fon-la plat é dé mwatyé-la ka anbwété yonn adan lòt.

Mi modèl V2 la. Sé koulè-la ka montré sé fòm-la ; ou pa bizwen pon pyès an métal.

- Grandè pa déwò a apépré 74 × 82 × 75 mm, fon plat é lékran panché a 30°.
- Wouvèti lékran-la : 46 × 25 mm ; plas-la préparé pou on kat ki miziré 32,6 mm an lajè é 5 mm an épésè.
- Pasaj USB pa anndan : 13 × 8 mm, pò-la a apépré 5,1 mm dè bout-la ; pasaj a 10 mm dèyè pou sé fil-la.
- Dé sipò ki fè kò èvè bwat-la, èvè 26 mm ant yo, pou dé vis M2 × 5 mm a tèt silendrik oben won, pa a tèt frazé.
- Dé mwatyé-la ka fèmé èvè kat clips, san lakòl ; ni 36 mm dèyè kat-la pou sé konektè Dupont la.

### Avan ou enprimé tout bwat-la

Enprimé gabari a kat-la é sé vis-la avan, èvè filaman-la ou ké sèvi pou bwat-la. Vérifyé wouvèti lékran-la, si sé tou-la byen anfas é si sipò-la ka pozé kon i fo asi sikwi-la. Gabari-la pa ka ripwodui tinèl USB la : apré ou enprimé mwatyé anho-la, vérifyé vré fich USB a-w ka rantré byen osi. Sé vérifikasyon nimerik a modèl-la pa ka ranplasé tès fizik lasa. Ou pé pa anbwété on mwatyé V1 èvè on mwatyé V2.

### Enprimé é monté-y

Inité : milimèt, échèl 100 %. Sé fichyé-la ja byen viré : mwatyé anba-la asi fon a-y, mwatyé anho-la asi fas-la koté sé dé mwatyé-la ka jwenn la, gabari-la èvè fas-la ou ka vwè la asi plato enprimant-la. Pou koumansé : biz a 0,4 mm, kouch a 0,20 mm, kat pawoi, senk kouch plen é 15–20 % ranplisaj. PETG ka ba sé clips-la plis souplès ; fè on tès èvè yo si ou chwazi PLA oben on filaman bwa.

Prévwè sé sipò-la anba pati bonbé la é sèten bò a mwatyé anho-la, é vérifyé sé pati a mwatyé anba-la ki ka dépasé san sipò. Woté sé bavir-la. Mété kat-la adan mwatyé anho-la, épi visé dousman dépi do a sikwi enprimé la adan sé dé ti tou a 1,6 mm la. Arété dépi kat-la ka kenbé : fò pa sé vis-la pliyé kat-la ni mété présyon asi vè-la.

Vérifyé fich USB la avan ou fèmé. On fich ki ni plastik alantou a-y a 6–7 mm an wotè ka lésé plis maj ki on fich a 8 mm. Branché sé Dupont-la, ranjé sé fil-la lwen sé clips-la é anbwété sé dé mwatyé-la. Sé bouton BOOT é EN la ka rété kòmann a kat-la, a pa bouton pou fè réglaj touléjou.

## Montaj é lantretyen téknik

Sé lenfòwmasyon-lasa sé pou moun-la ki ka monté oben antretni léktwonik-la. Si ou risivwè on barik ki ja paré, ou pa bizwen sa pou sèvi èvè-y.

### Montaj-la yo ka sèvi èvè-y alè : on HX711 tousèl

Montaj-la ki la alè ka sèvi èvè on kat ideaspark ESP32-WROOM-32 èvè lékran ST7789 1,9″ é on HX711. Kat dimi-sélil a chaj ka fè ansanm on sèl pon mizir ; a pa kat kanal ki ka maché chak apa.

HX711 | Kat ideaspark
VCC | 3V3
GND | GND an komen
DT / DOUT | GPIO 25
SCK | GPIO 26

HX711 la ka risivwè 3,3 V, menm si kat-la ka risivwè 5 V pa USB. Pa branché sòti lojik a-y alimanté an 5 V asi sé broch a ESP32 la. Gadé fich kab-la avan ou touché montaj-la.

### Ondòt montaj : dé HX711

Ondòt montaj ka sèvi èvè dé sélil a pon konplé, èvè on HX711 pou chak sélil. Asi kat ideaspark la, dézyèm modil-la ka sèvi èvè GPIO 16 pou DT é GPIO 17 pou SCK. Pou fè sa, fò ou pasé NUM_CHANNELS dè 1 a 2, rikompilé é woufè réglaj a balans-la. Schéma a montaj-lasa pa ka montré koneksyon a chak adan sé kat dimi-sélil a montaj aktif la.

### Mété lojisyèl-la ajou

Èvè on kopi a pwojé-la é PlatformIO ki ja enstalé, branché kat-la an USB épi sèvi èvè sé kòmann-la ki anba-la. Lojisyèl-la ja ni aplikasyon web la adan ; ou pa bizwen voyé sé fichyé web la apa.

make ports       # jwenn kat USB la
make build       # konpilé pou kat ideaspark la
make upload      # enstalé lojisyèl-la
make monitor     # li dyagnostik-la ; sòti èvè Ctrl-C

Si lenstalasyon-la ka rété asi Connecting…, kenbé BOOT apiyé lè ou ka lanse télévèsman-la, épi lagé-y lè aparèy-la ka koumansé maké lojisyèl-la. make build-all ka konpilé sé dé vèsyon OLED la ki adan pwojé-la osi. Yo pa ni menm brochaj-la : vérifyé ki kat ou ka vizé avan ou enstalé ayen.

Lè ou ka mété lojisyèl-la ajou, i pé gadé sé réglaj-la, mé sa pa garanti si fòma a yo chanjé. Apré ou fin travay asi-y, vérifyé rézo-la, pwa-la, sé référans-la é Telegram avan ou rimèt barik-la an sèvis.

### Lenfòwmasyon pou ba moun-la ki ka édé-w la

Maké sa ki pa ka maché la, sé dènyé biten-la ou fè la é sa « Réglages → Système » ka montré : léta a HX711 la é si lè-la senkronizé. Pou on dyagnostik téknik, paj lokal http://rum.local/api/state la ka montré sé mizir brit la é léta a aparèy-la. I pé ni non a barik-la é idantifyan a konvèsasyon Telegram la adan : kaché sé biten-lasa avan ou patajé paj-la èvè tout moun.

RumScale · Lanèks téknik
Vérifyé 30 sèptanm 2026.

Viré adan manyèl-la ↗Pwojé-la asi GitHub ↗ (https://github.com/pbouffaut/RumScale)Viré anho ↑

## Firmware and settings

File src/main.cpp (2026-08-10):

// RumScale — un tonneau de vieillissement qui sait ce qu'il lui reste dedans.
//
//   deux HX711 sous une base  ->  poids  ->  niveau, services, part des anges
//   écran OLED + bouton       ->  niveau, jours de vieillissement, remise à zéro
//   app web + WebSocket       ->  suivi en direct, historique, initialisation
//   Telegram                  ->  alertes quand le niveau baisse

#include <Arduino.h>
#include "config.h"
#include "store.h"
#include "scale.h"
#include "history.h"
#include "barrel.h"
#include "notify.h"
#include "ui.h"
#include "net.h"

void setup() {
  Serial.begin(115200);
  delay(300);
  Serial.println(F("\n=== RumScale ==="));

  Store::begin();
  Ui::begin();
  Ui::showBootMessage("RumScale", "Démarrage…");

  Scale::begin();
  History::begin();
  Notify::begin();
  Barrel::begin();

  Net::begin();       // bloque le temps du portail de configuration, si besoin

  Serial.println(F("[main] prêt"));
}

void loop() {
  Scale::update();    // ne lit un HX711 que lorsqu'une conversion est prête
  Barrel::update();   // paliers, événements, historique
  Ui::loop();         // écran et bouton
  Net::loop();        // WebSocket, redémarrages différés
  Notify::loop();     // file Telegram

  delay(2);           // laisse la main aux tâches Wi-Fi
}

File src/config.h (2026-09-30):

#pragma once
#include <Arduino.h>

// ============================================================================
//  Brochage — choisi par l'environnement PlatformIO (voir platformio.ini).
//  Mets PIN_LED à -1 si la carte n'a pas de LED simple : sur la plupart des
//  cartes ESP32-S3, la LED embarquée est une WS2812 adressable, qu'un
//  digitalWrite ne sait pas piloter.
// ============================================================================

#if defined(BOARD_TFT_ST7789)

// ideaspark ESP32-WROOM-32 avec écran couleur ST7789 1,9" 170x320.
// L'écran occupe des GPIO câblés en dur sur la carte : 23 (MOSI), 18 (SCK),
// 15 (CS), 2 (DC), 4 (RST), 32 (rétroéclairage). Il ne faut donc surtout pas
// reprendre le brochage OLED, qui utilisait 2 et 4.
  #define PIN_TFT_MOSI  23
  #define PIN_TFT_SCK   18
  #define PIN_TFT_CS    15
  #define PIN_TFT_DC     2
  #define PIN_TFT_RST    4
  #define PIN_TFT_BL    32

  #define TFT_W        170
  #define TFT_H        320
// Une dalle de 170 px de large sur un contrôleur ST7789 câblé pour 240 px doit
// être décalée. Si l'image apparaît glissée horizontalement, c'est ici que ça
// se règle — les valeurs vues en pratique sont 35 ou 0.
  #define TFT_COL_OFFSET 35
  #define TFT_ROW_OFFSET  0

// Rétroéclairage, 0..255. À fond, l'écran chauffe — et la chaleur fait dériver
// les cellules de charge posées juste en dessous. 170 reste très lisible.
  #define TFT_BACKLIGHT 170

// Le pont complet formé par les quatre demi-cellules utilise un seul HX711,
// câblé sur D25/D26. GPIO 16/17 restent disponibles pour une extension future.
  #define PIN_HX_A_DOUT 25
  #define PIN_HX_A_SCK  26
  #define PIN_HX_B_DOUT 16
  #define PIN_HX_B_SCK  17

  #define PIN_BUTTON    27   // bouton vers GND, pull-up interne
  #define PIN_LED       -1   // pas de LED libre sur cette carte

#elif defined(BOARD_S3)

// ESP32-S3 nu (Waveshare ESP32-S3-DEV-KIT, Freenove ESP32-S3-WROOM).
// À éviter absolument sur ces modules : GPIO 26..32 (flash interne) et
// GPIO 33..37, mangés par la PSRAM octale des versions « R8 ». GPIO 19/20 sont
// l'USB natif, 43/44 la console série, 0/45/46 des straps de boot.
  #define PIN_HX_A_DOUT  4
  #define PIN_HX_A_SCK   5
  #define PIN_HX_B_DOUT  6
  #define PIN_HX_B_SCK   7

  #define PIN_I2C_SDA    8
  #define PIN_I2C_SCL    9

  #define PIN_BUTTON    10   // bouton vers GND, pull-up interne
  #define PIN_LED       -1   // LED embarquée adressable : on ne s'en sert pas

#else

// ESP32 WROOM-32 DevKit.
// À éviter : GPIO 6..11 (flash interne), GPIO 0 / 2 / 12 / 15 (straps de boot).
// Les GPIO 34..39 sont en entrée seule : parfaits pour DOUT, inutilisables pour SCK.
  #define PIN_HX_A_DOUT 16
  #define PIN_HX_A_SCK   4
  #define PIN_HX_B_DOUT 17
  #define PIN_HX_B_SCK   5

  #define PIN_I2C_SDA   21
  #define PIN_I2C_SCL   22

  #define PIN_BUTTON    27
  #define PIN_LED        2

#endif

// Les quatre demi-cellules forment ensemble un pont complet lu par un HX711.
#define NUM_CHANNELS   1

// ============================================================================
//  Échantillonnage et filtrage
// ============================================================================

// Le HX711 sort 10 mesures/seconde (broche RATE à la masse, réglage d'usine).
static const uint8_t MEDIAN_WINDOW = 15;     // médiane glissante, ~1,5 s
static const float   EMA_ALPHA     = 0.08f;  // lissage exponentiel derrière

// Écran : le contrôleur reste éveillé pour continuer à peser et détecter deux
// coups brefs sur la base ; seul le rétroéclairage est coupé.
static const uint32_t TAP_WINDOW_MS    = 1200;
static const uint32_t TAP_LOCKOUT_MS   = 250;
static const int32_t  TAP_MIN_COUNTS   = 5000;

// ============================================================================
//  Détection d'événements
//
//  On ne se fie jamais au poids absolu instantané : sur des mois, une cellule de
//  charge dérive (température, fluage du métal). On raisonne donc en *paliers* —
//  le poids se stabilise, on compare au palier précédent, et l'écart devient un
//  événement. Une baisse rapide est un service ; une baisse très lente est de
//  l'évaporation (la « part des anges »).
// ============================================================================

static const float    STABLE_BAND_G   = 12.0f;   // amplitude tolérée pour un palier
static const float    STABLE_EXIT_G   = 20.0f;   // hystérésis visuelle : ignore la dérive lente
static const uint32_t STABLE_MS       = 20000;   // durée de calme avant de figer le palier
static const float    EVENT_MIN_G     = 25.0f;   // plus petit écart qui mérite un événement
static const float    EVAP_MAX_G_DAY  = 25.0f;   // au-delà, ce n'est plus de l'évaporation

// Un verre posé sur la base produit une hausse puis une baisse équivalentes.
// On attend un peu avant de confirmer un événement, le temps de voir venir son
// éventuel opposé.
static const uint32_t EVENT_CONFIRM_MS = 180000UL;  // 3 minutes
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

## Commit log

2026-08-10 Tonneau de vieillissement connecté : firmware, app web et documentation
    Deux cellules de charge sous une base pèsent le tonneau en continu. Le firmware
    en déduit le volume restant, les jours de vieillissement et les services, sert
    une app web depuis l'ESP32, et alerte par Telegram.
    Le niveau ne se lit jamais sur le poids absolu : une cellule de charge dérive
    sur des mois. On raisonne en paliers stabilisés, dont les écarts deviennent des
    événements — service, remplissage, ou part des anges selon leur vitesse.
    Trois cibles matérielles partagent le code : carte ideaspark à écran ST7789
    couleur, ESP32-WROOM ou ESP32-S3 à écran OLED.
    Aucune partie n'a encore tourné sur du maté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
    [barrel.cpp, config.h, history.cpp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]
2026-08-10 README : lien vers le schéma de câblage
2026-09-30 Mettre à jour le firmware et ajouter le boîtier tonneau V2
    Intégrer le montage à un HX711, la veille réglable avec réveil par double coup, les diagnostics et la stabilisation de l'affichage. Aligner le câblage documenté sur le montage actuel.
    Ajouter les cinq STL V2, le modèle paramétrique, le guide, les aperçus et le pack ZIP vérifié. Exclure les fichiers temporaires de conception.
    Validation : compilation des trois cibles PlatformIO, syntaxe Python et JavaScript, liens README, archive ZIP et empreintes des cinq STL.
    [01_demi_tonneau_bas_v2.stl, 02_demi_tonneau_haut_v2.stl, 03_gabarit_carte_et_vis_v2.stl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]
2026-09-30 Ajouter le guide de configuration et la FAQ pour GitHub Pages
    Documenter la connexion Wi-Fi, la calibration, les alertes Telegram, les remises à zéro, le transfert du tonneau et les limites hors ligne. Ajouter 24 réponses recherchables, une navigation mobile, u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
    Vérification : relecture contre le firmware, liens locaux, tests navigateur de 320 à 1440 px, recherche avec accents, accordéons, navigation et contenu sans JavaScript.
2026-09-30 Adapter le manuel au destinataire du tonneau dans les trois langues
